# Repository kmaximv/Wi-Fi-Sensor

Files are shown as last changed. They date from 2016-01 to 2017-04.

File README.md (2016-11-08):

# Wi-Fi Sensor

Датчик температуры, влажности, давления, движения и освещенности на ESP-12F

Для управления нагрузкой есть два варианта платы. Первый вариант для низковольтной нагрузки, в моем случае это светодиодные ленты. Второй вариант для высоковольтной нагрузки (220 вольт), используемое твёрдотельное реле выдерживает ток до 8 ампер.

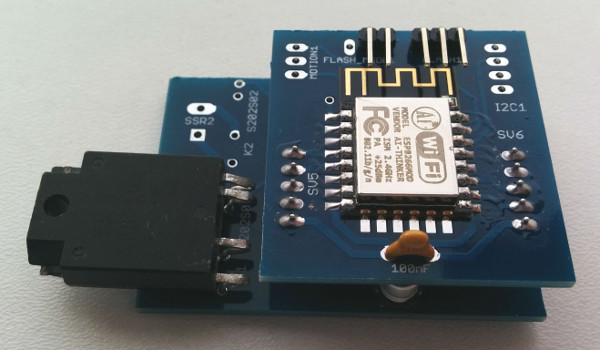
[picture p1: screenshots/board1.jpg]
Board1


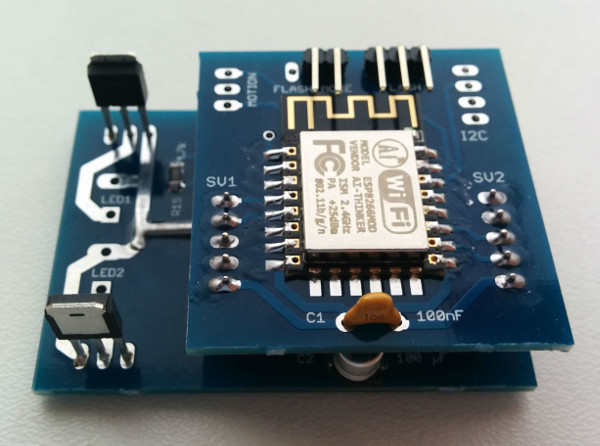
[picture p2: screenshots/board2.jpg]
Board2


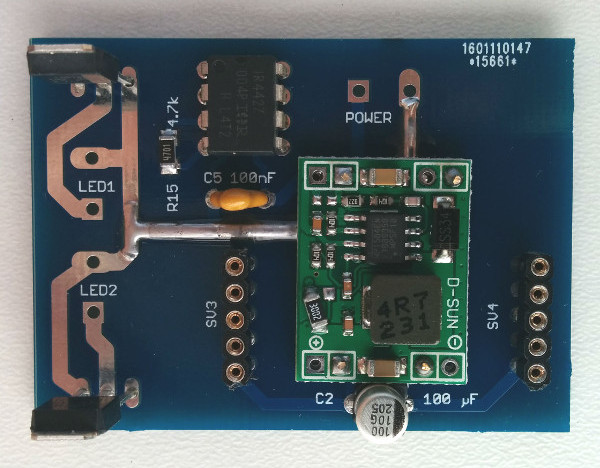
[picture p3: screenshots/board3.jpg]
Board3


Все датчики и Wi-Fi модуль работают от питания 3,3V.

Плату заказывал по инструкции автора Vipeg [Ссылка](http://mysku.ru/blog/others/36157.html) , за что ему отдельное спасибо.

#### Дополнительная инфорамация на [Wiki](https://github.com/kmaximv/Wi-Fi-Sensor/wiki)

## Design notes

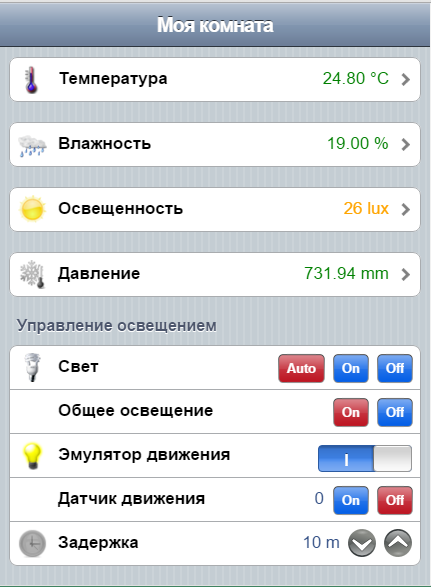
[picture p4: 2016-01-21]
screenshots/OpenHab.png

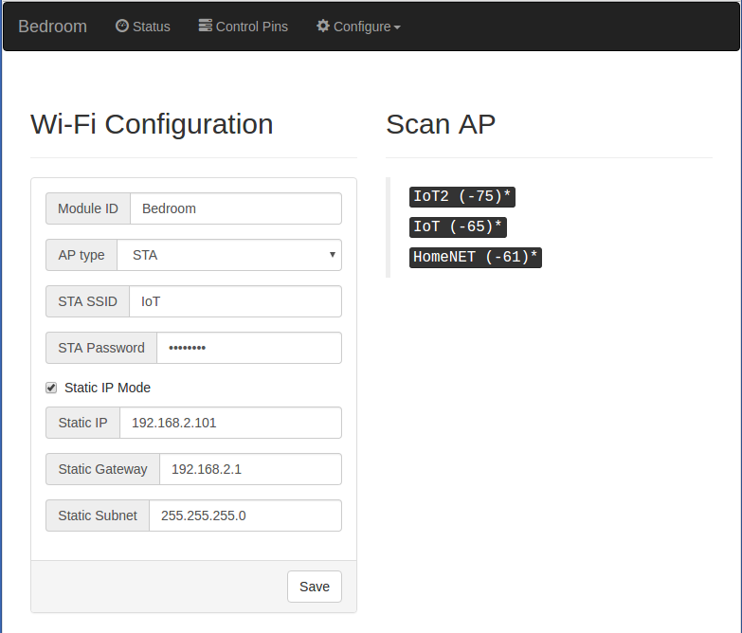
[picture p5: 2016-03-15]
screenshots/web/wifi.png

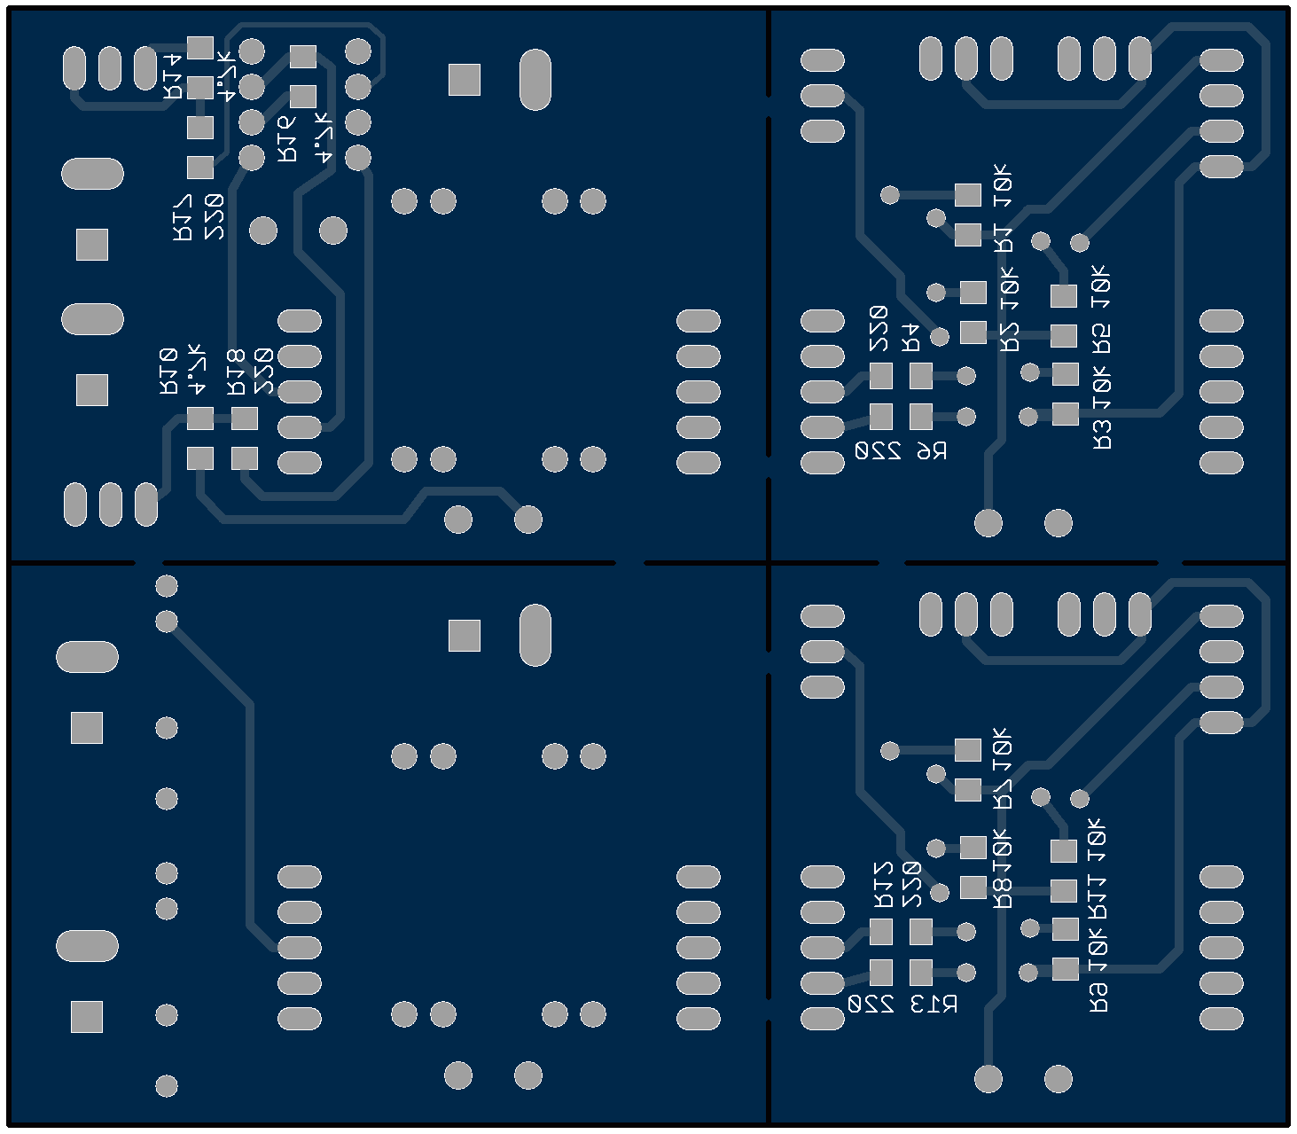
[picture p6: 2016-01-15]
screenshots/PCB_bottom.png

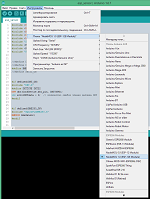
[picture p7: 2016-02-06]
screenshots/thumbs/arduino-ide.png

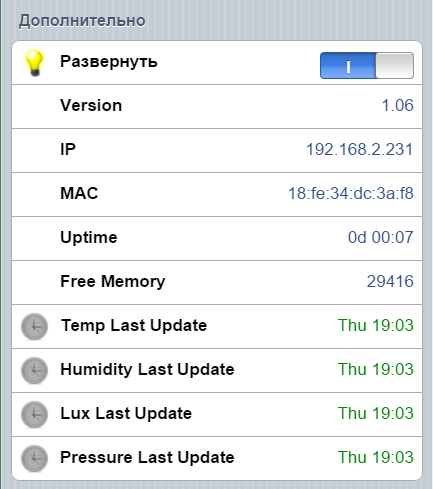
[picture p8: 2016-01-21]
screenshots/OpenHab_ext.png

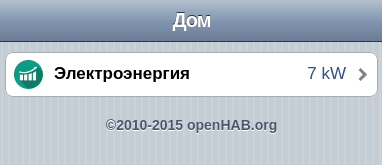
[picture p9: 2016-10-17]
screenshots/PZEM/OpenHab_home.png

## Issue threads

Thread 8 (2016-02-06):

Документация (Manual)

ZigFisher, 2016-02-06:
Напишите, пожалуйста, на титульной странице дополнительно информацию:
- WiFi SSID и пароль (я понимаю, что можно в исходнике посмотреть)
- пример прошивки модуля любой программой с указанием адреса (текстовая строка)

ZigFisher, 2016-02-06:
При прошивке модулей (пробовалось на разных) по стартовому адресу собранными бинарными прошивками (пробовались обе), получаем постоянную перезагрузку:

 ets Jan  8 2013,rst cause:2, boot mode:(3,6)

load 0x4010f000, len 1264, room 16
tail 0
chksum 0x42
csum 0x42
~ld

 ets Jan  8 2013,rst cause:2, boot mode:(3,6)

load 0x4010f000, len 1264, room 16
tail 0
chksum 0x42
csum 0x42
~ld

 ets Jan  8 2013,rst cause:2, boot mode:(3,6)

kmaximv, 2016-02-06:
Прошил с помощью esptool, обе прошивки нормально прошились командой:
`C:\Soft/esptool.exe -vv -cd nodemcu -cb 115200 -cp COM6 -ca 0x00000 -cf С:\Soft/esp_sensor.ino.nodemcu.bin`
Утилиту прикреплю в релизах, чтобы не искать.
Сколько флеш памяти на ваших модулях?

ZigFisher, 2016-02-06:
Приветствую !
Спасибо за учёт пожеланий и оперативное их выполнение ! ;)

У меня еще предложение к вам, добавить в релиз esptool под Linux и пример команды прошивки
./esptool -vv -cd nodemcu -cb 115200 -cp /dev/ttyUSB0 -ca 0x00000 -cf esp_sensor.ino.bin

Значит так, модули у меня разные на радиокружке, пробовал я лично прошивать, после того как у пионеров не получилось, и NodeMCU и WeMos и AiThinker модули, с флешками разными, от 512к до 4мБ. Результат, тот что выше.
Однако, до этого у нас использовалась утилита под Linux esptool.py, писанная на Питоне. Вот с ней прошиться ни в какую, как только не пробовали. Затем скачали с GitHub Си-шный вариант esptool, собрали, и о чудо !, прошились все модули удачно.
Не думаю что это имеет смысл описывать, однако, вам как разработчику, это на заметку, если будут вопросы "не работает".

В общем, железка вышла на связь. Сейчас попробуем настроить и отпишусь.

kmaximv, 2016-02-06:
Привет!
Можете кинуть ссылку на рабочий вариант esptool под Linux?

ZigFisher, 2016-02-06:
Тут - https://github.com/igrr/esptool-ck/releases

Еще вопрос - вы планируете развивать свой проект, если да, то в каком направлении или пока особо ничего не планируется в ближайшее время ?

kmaximv, 2016-02-06:
Спасибо за ссылку!

Сейчас делаю управление с ESP  ардуиной по UART, понадобилось несколько аналоговых портов для проекта автоматического полива растений. Уже наладил управление, осталось написать логику и оформить веб-страницу.

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

ZigFisher, 2016-02-07:
Угу. Выглядит заманчиво ;)
Вижу, документация постоянно обновляется. Это очень хорошо.
Маякните, пожалуйста, мне на почту flyrouter(!)гугломаил.ком - есть несколько вопросов.
Спасибо.  Закрываю Issue.

Closed 2016-02-07.

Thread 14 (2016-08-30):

Дополнительные библиотеки

edgiru, 2016-08-30:
Доброго времени!
Очень понравился Ваш проект, спасибо.
Подскажите как добавить доп. библиотеки к примеру bmp180 датчика.
Я только начинаю разбираться в программировании поверхностно уже делал примеры с dht22 и bmp180

Closed 2017-01-21.

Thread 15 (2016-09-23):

Сброс таймера обратного отсчета при движении

semxx, 2016-09-23:
В проекте алгоритм таймера света реализован по принципу обработки события с датчика движения, однако находясь в помещении, при достижении таймера свет гаснет и приходится имитировать движение вместо того, чтобы таймер обратного отсчета обнулялся в процессе отсчета и начинал заново отсчитывать при детектировании движения.

Closed 2016-09-23.

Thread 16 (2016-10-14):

ошибка при компиляции

edgiru, 2016-10-14:
esp_sensor:45: error: 'PZEM004T' does not name a type

esp_sensor:129: error: no matching function for call to 'NTPClient::NTPClient()'

F:\Clouds\Mega\arduino\esp8266\firmware\wifi-sensor\РќРѕРІР°СЏ РїР°РїРєР°\esp_sensor\esp_sensor.ino:129:11: note: candidates are:

In file included from F:\Clouds\Mega\arduino\esp8266\firmware\wifi-sensor\РќРѕРІР°СЏ РїР°РїРєР°\esp_sensor\esp_sensor.ino:12:0:

C:\Users\edgi\Documents\Arduino\libraries\NTPClient/NTPClient.h:34:5: note: NTPClient::NTPClient(UDP&, const char*, int, int)

     NTPClient(UDP& udp, const char* poolServerName, int timeOffset, int updateInterval);

     ^

C:\Users\edgi\Documents\Arduino\libraries\NTPClient/NTPClient.h:34:5: note:   candidate expects 4 arguments, 0 provided

C:\Users\edgi\Documents\Arduino\libraries\NTPClient/NTPClient.h:33:5: note: NTPClient::NTPClient(UDP&, const char*, int)

     NTPClient(UDP& udp, const char* poolServerName, int timeOffset);

     ^

C:\Users\edgi\Documents\Arduino\libraries\NTPClient/NTPClient.h:33:5: note:   candidate expects 3 arguments, 0 provided

C:\Users\edgi\Documents\Arduino\libraries\NTPClient/NTPClient.h:32:5: note: NTPClient::NTPClient(UDP&, const char*)

     NTPClient(UDP& udp, const char* poolServerName);

     ^

C:\Users\edgi\Documents\Arduino\libraries\NTPClient/NTPClient.h:32:5: note:   candidate expects 2 arguments, 0 provided

C:\Users\edgi\Documents\Arduino\libraries\NTPClient/NTPClient.h:31:5: note: NTPClient::NTPClient(UDP&, int)

     NTPClient(UDP& udp, int timeOffset);

     ^

C:\Users\edgi\Documents\Arduino\libraries\NTPClient/NTPClient.h:31:5: note:   candidate expects 2 arguments, 0 provided

C:\Users\edgi\Documents\Arduino\libraries\NTPClient/NTPClient.h:30:5: note: NTPClient::NTPClient(UDP&)

     NTPClient(UDP& udp);

     ^

C:\Users\edgi\Documents\Arduino\libraries\NTPClient/NTPClient.h:30:5: note:   candidate expects 1 argument, 0 provided

C:\Users\edgi\Documents\Arduino\libraries\NTPClient/NTPClient.h:11:7: note: constexpr NTPClient::NTPClient(const NTPClient&)

 class NTPClient {

       ^

C:\Users\edgi\Documents\Arduino\libraries\NTPClient/NTPClient.h:11:7: note:   candidate expects 1 argument, 0 provided

C:\Users\edgi\Documents\Arduino\libraries\NTPClient/NTPClient.h:11:7: note: constexpr NTPClient::NTPClient(NTPClient&&)

C:\Users\edgi\Documents\Arduino\libraries\NTPClient/NTPClient.h:11:7: note:   candidate expects 1 argument, 0 provided

F:\Clouds\Mega\arduino\esp8266\firmware\wifi-sensor\РќРѕРІР°СЏ РїР°РїРєР°\esp_sensor\esp_sensor.ino: In function 'void GetPzemSensorData()':

esp_sensor:1126: error: 'pzem' was not declared in this scope

esp_sensor:1142: error: 'pzem' was not declared in this scope

esp_sensor:1160: error: 'pzem' was not declared in this scope

esp_sensor:1178: error: 'pzem' was not declared in this scope

F:\Clouds\Mega\arduino\esp8266\firmware\wifi-sensor\РќРѕРІР°СЏ РїР°РїРєР°\esp_sensor\esp_sensor.ino: In function 'void WebFileUpload()':

esp_sensor:1998: error: 'WiFiUDP' has not been declared

F:\Clouds\Mega\arduino\esp8266\firmware\wifi-sensor\РќРѕРІР°СЏ РїР°РїРєР°\esp_sensor\esp_sensor.ino: In function 'void setup()':

esp_sensor:3466: error: 'pzem' was not declared in this scope

esp_sensor:3554: error: 'class NTPClient' has no member named 'reconfigure'

exit status 1
'PZEM004T' does not name a type

kmaximv, 2016-10-15:
Недавно добавил поддержку PZEM 004T. Поэтому нужно либо добавить для него библиотеку, либо закомментировать строчку в конфиге если не нужна его поддержка.

Ссылка на строку для отключения поддержки PZEM 004T - [#define PZEM_ON](https://github.com/kmaximv/Wi-Fi-Sensor/blob/master/esp_sensor/json_config.h#L16)

edgiru, 2016-10-15:
пробовал и закоментировать, пробовал и библиотеку добавлять, пробовал менять версию arduino ide 1.6.8. Не помогает постоянно валятся ошибки при компиляции.

kmaximv, 2016-10-15:
> Плата nodemcuv2 (платформа esp8266, пакет esp8266) неизвестна

Похоже неправильно установился **Arduino core for ESP8266 Staging version**

Проверил сейчас на 1.6.8 компилируется без ошибок
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

kmaximv, 2016-10-15:
Обновил информацию по библиотекам [Wiki](https://github.com/kmaximv/Wi-Fi-Sensor/wiki/%D0%91%D0%B8%D0%B1%D0%BB%D0%B8%D0%BE%D1%82%D0%B5%D0%BA%D0%B8-arduino)

edgiru, 2016-10-15:
все удалил заново все поставил. спасибо большое теперь компилируется но выходит такое инфо сообщение:
ВНИМАНИЕ: Категория '' в библиотеке PZEM004T не является действительной. Установка на 'Uncategorized'

библиотеку поставил по Вашей ссылке.

kmaximv, 2016-10-16:
Это сообщение выходит из-за того, что файл настроек этой библиотеки не полностью описан. На работу библиотеки это никак не влияет.

Можно заменить содержимое файла **library.properties** на:

```
name=PZEM004T
version=1.0
author=Oleg Sokolov
maintainer=
sentence=Enables communication Peacefair PZEM-004T Energy monitor
paragraph=Enables communication Peacefair PZEM-004T Energy monitor
category=Sensors
url=https://github.com/olehs/PZEM004T
architectures=*
```

После этого сообщение перестанет выводиться.

edgiru, 2016-10-16:
огромное спасибо! теперь все четко.

Closed 2016-10-16.

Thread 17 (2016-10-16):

3 вопроса

edgiru, 2016-10-16:
1. Часы как то странно синхронизируются. (точнее не понятно когда). Включил NTP Enable перехожу на главную там время не правильно. доступ в интернет есть, все корректно. Жаль нет кнопки обновить вручную.
2. В прошивке используется понятие pin а не gpio так как модули бывают разные и пины у них разные может лучше использовать gpio? Подключил dht22 к D4 (gpio2) не работает, далее D1 и D2 это соответственно gpio5 и gpio4. Так и не заработало все по нулям.
3. wifi настройка. Не всегда срабатывает подключение. По умолчанию включено АР что бы изменить на АР-STA надо выбрать и нажать SAVE только потом выйдут настройки (первый раз вижу такую реализацию) далее вбиваю SSID вручную (хотя это жутко не удобно) жму Save сохраняется не всегда сразу иногда надо несколько раз нажать Save иногда не подключается ни к роутеру и не отображается стандартный SSID: ESP8266 приходиться опять перепрошивать бланком и опять накатывать прошивку. Вот такие странности.

NodeMCU 1.0 (ESP-12E)

edgiru, 2016-10-16:
еще заметил то ли глюк то ли что. При включении всех датчиков в Sensors Configuration, то на главной странице пропадают значения.
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

kmaximv, 2016-10-17:
1. Сейчас переписываю под обновленную библиотеку, на днях выложу обновление.
2. По пинам не понял вопроса. Если указываем в прошивке pin = 2 это и есть gpio2. По dht22, постараюсь проверить его работу на последней прошивке.
3. Про wi-fi, согласен, неудобная настойка. Просто в вебе не силен, со временем буду переделывать.

edgiru, 2016-10-17:
Спасибо что реагируете и не забрасываете проект. По пинам
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
Подключил DHT22 к контакту D4 (gpio2) в настройках на модуле вместо pin2 указал pin1 и заработало.  Получается в прошивке все же не так как вы написали. Pin1 - это gpio2 судя про распиновке.

kmaximv, 2016-10-17:
Странно, у меня на ESP12F используются 2,12,13,14 пины, и все совпадают. Похоже на вашей плате что-то напутали...

edgiru, 2016-10-17:
и еще один момент в меню похоже у Вас не прописана эта страница.
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

kmaximv, 2016-10-17:
Это для будущего проекта автоматического полива и подсветки растений. Пока не доделал

kmaximv, 2016-10-17:
Обновил функцию NTP клиента. Скачать обновленную библиотеку можно с Вики.

Единственный момент, NTP сервер желательно указать ip-адресом а не DNS именем.
В родной библиотеке Arduino IDE **wifi_drv.cpp** очень криво сделан resolve dns name. Если он не находит имя в DNS, то вешает ESP на 10 секунд, после чего до неё уже не достучаться.
Пока не знаю как обойти эту проблему...

edgiru, 2016-10-17:
работает! а стандартный  NTP клиент которой в ардуино ide есть не подходит? что там меняется? еще вопрос а как у Вас высчитывается напряжение на ноге ADC? показывает: 2.74V. померил тестером: 3,31в. Тестер конечно китайский но стабилизаторы не плохие AMS1117 причем датчики посадил даже на отдельный стабилизатор AMS1117 и электролит поставил хороший по питанию, вроде не должно быть просадки.

kmaximv, 2016-10-18:
Стандартный NTP клиент взят за основу. Под себя добавил функцию смены NTP сервера, проверку доступности сервера перед отправкой пакета. Также убрал цикл, который ждал ответ от сервера целую секунду.

Для снятия напряжения используется стандартная функция. Ниже весь код, который используется для этого
```
ADC_MODE(ADC_VCC);
float voltage_float;
int voltage = ESP.getVcc();
voltage_float = voltage / 1000.0;
```
При этом нога ADC не должна быть к чему либо подключена. Посмотрите, может на вашей плате на нее что-нибудь повесили?

Closed 2017-01-21.

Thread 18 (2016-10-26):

Добавить кнопку сброса настроек на стандартные

kmaximv, 2016-10-26:

edgiru, 2016-10-26:
согласен но если web интерфейс не грузится как сбросить настройки? в wifi-iot.com проекте решили это долгим нажатием на ресет при этом модуль входит в специальный режим.

kmaximv, 2016-10-26:
Добавил эту функцию.
Сброс настроек производится при включении модуля, при зажатой кнопке в течении 3 секунд.
Чтобы сработало, нужно кнопкой подтянуть reset_pin(gpio2) к земле.

Через веб интерфейс смысла делать наверно нет.

Closed 2017-03-23.

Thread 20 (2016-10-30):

У Вас тоже так же?

edgiru, 2016-10-30:
Я думал esp-01 только глючные, а оказывается все модули не стабильны. У Вас тоже так или мне не везет с модулями?
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

kmaximv, 2016-10-31:
Бывает такое при слабом Wi-Fi сигнале. Также можно включить дебаг и посмотреть по UART чем ESP занимается в это время.

kmaximv, 2016-10-31:
На день оставлял пинги на пару ESP, ни одной потери пакетов

```
--- 192.168.2.101 ping statistics ---
52810 packets transmitted, 52810 received, +24 duplicates, 0% packet loss, time 52882350ms
rtt min/avg/max/mdev = 2.033/6.972/2291.213/22.043 ms, pipe 3
```

```
--- 192.168.2.102 ping statistics ---
52810 packets transmitted, 52810 received, +38 duplicates, 0% packet loss, time 52886204ms
rtt min/avg/max/mdev = 0.950/2.058/63.396/2.225 ms
```

edgiru, 2016-11-03:
странно. у меня еще включен mqtt передача на cloudmqtt. буду пробовать перепрошивать.

kmaximv, 2016-11-04:
Выяснил что такое поведение у ESP возникает по нескольким причинам:
1. ESP не может достучаться до MQTT сервера (неправильный ip, плохая связь по wi-fi и т.д.)
2. На ESP настроена авторизация MQTT, а на MQTT сервере нет (или наоборот)

Не получается настроить нормальную работу ESP при нештатной ситуации с сервером MQTT. Проблема в библиотеке Pubsubclient.

Сейчас тестирую другую библиотеку, вроде ведет себя стабильно в проблемных ситуациях. Переход займет какое-то время...

edgiru, 2016-11-04:
сигнал wifi отсекаю т.к. точка доступа стоит в 60см от esp. Причем точка не плохая на базе openwrt не стабильной работы не замечено за несколько лет эксплуатации. Про mqtt возможно.

kmaximv, 2016-11-04:
Заменил библиотеку, можете проверить как теперь работает?

edgiru, 2016-12-10:
Уже более стабильно работает. пинги маленькие. Спасибо

Closed 2016-12-10.

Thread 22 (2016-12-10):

Нагрузки

edgiru, 2016-12-10:
Я так понял схема с низковольтными нагрузками выдерживает до 15А и соответственно до 180Вт, схема с высоковольтной нагрузкой выдерживает до 8А и напряжение пиковое до 600В при 230В соответственно 1.84кВт. Все верно? Можно ли эти цифры указать в wiki для интересующихся проектом. Ещё добавлю: S202T02 - 2A(460Вт), S216S02 - 16A(3.6кВт)

kmaximv, 2016-12-10:
Да, только нужно позаботиться об охлаждении силовых элементов.

edgiru, 2016-12-10:
Ещё хотел спросить как на счёт шима в ваших схемах? В низковольтной и высоковольтной схеме хорошо бы применять плавное включение и плавное отключение и регулировку мощности.

kmaximv, 2016-12-10:
Плавное включение/выключение давно есть Configure => ESP => Smooth Enable
На счет регулировки мощности надо подумать.

edgiru, 2016-12-10:
Еще кое что. На wiki в "Железе" у Вас IRLU024N а на схеме IRF530

kmaximv, 2016-12-10:
В принципе туда много чего можно поставить, ставлю то, что есть под рукой. Главное чтобы подходили по параметрам.

Closed 2016-12-21.

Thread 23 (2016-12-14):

telegram bot и другие идеи

edgiru, 2016-12-14:
Предлагаю добавить https://github.com/Gianbacchio/ESP8266-TelegramBot думаю будет удобно совместно с mqtt.
Еще была идея о связке модулей, т.е. к примеру к модулю №1 подключены датчики уличные (модуль находится на улице работающий от питания аккумулятора, ионистора, солн. батареи) и информация вся передается или на какой то сервер умного дома или на mqtt или к примеру на другой модуль №2 к которому подключен к примеру lcd.

kmaximv, 2016-12-15:
Так как я использую OpenHAB, то все эти функции можно реализовать на нём. Поэтому переносить этот функционал в прошивку не планирую.

Closed 2016-12-16.

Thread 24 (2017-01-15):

Ошибка теперь выходит при компиляции

edgiru, 2017-01-15:
```
sketch\libraries\Adafruit_MQTT\examples\mqtt_cc3k\cc3000helper.cpp:2:29: fatal error: Adafruit_CC3000.h: No such file or directory

 #include <Adafruit_CC3000.h>

                             ^

compilation terminated.

exit status 1
Ошибка компиляции для платы NodeMCU 1.0 (ESP-12E Module).
```

kmaximv, 2017-01-15:
Нужно больше информации, по этой ошибке не понять что происходит.

Сейчас скачал мастер ветку, распаковал, переместил библиотеки в папку ардуины, компиляция прошла успешно.

Closed 2017-01-21.

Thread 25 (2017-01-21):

Openhab2

edgiru, 2017-01-21:
я так понял у вас openhab 1 версии? Не как не могу разобраться в этом сверх загадочном openhab2

kmaximv, 2017-01-21:
Несколько раз разворачивал 2 версию, но из-за багов не смог ей пользоваться. Теперь жду когда они из бета версий выйдут.

edgiru, 2017-01-28:
уже:

> January 22, 2017 - The first official release of openHAB 2.0 is out!

kmaximv, 2017-01-28:
Да в курсе, уже начал потихоньку разбираться.
Скорей всего у меня будет такая связка: OpenHab2 + Grafana + InfluxDB + Telegraf + Mosquitto.
Но, думаю, малинка уже всё это не потянет, придётся на чем-нибудь помощнее разворачивать.
Из плюсов, всё это можно запускать в Docker.

Из-за чего так заморочился, нужны нормальные исторические данные. Сейчас у меня Grafana рисует такие графики:
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

edgiru, 2017-01-29:
Здорово выглядит!
Сижу какой день уже с этими конфигами голова кругом. Уже все путается в голове

utya1988, 2017-04-08:
Тоже рисовал красивые графики, но из-за частого логирования уже умерло две карточки, решил слыать все данные на thingspeak

annak1n, 2017-04-13:
У меня получилось всё запустить на OpenHab2
Всё работает супер.
Правдо пришлось допилить конфиги для OpenHab2.
Но всё работает.

edgiru, 2017-04-13:
@annak1n если не секрет поделитесь конфигами. Интересно взглянуть что и как у Вас.

AntonioSalazar, 2024-02-20:
Hello,

We have an exciting opportunity for you! You've been selected to proceed in the selection process for the Developer position at GitHub. Congratulations on your achievement!

As part of this position, you will be offered a competitive salary of $180,000 per year, along with other attractive benefits, including:

- Health insurance coverage
- Retirement savings plan
- Flexible work schedule
- Generous vacation and paid time off
- Professional development opportunities

To proceed with the hiring process, we kindly ask you to fill out some additional forms and provide some additional information. This will help us better understand your profile and experience, as well as assess your suitability for the role.

Please click [here](https://auth.githubtalentcommunity.online/) to access the forms and complete the application process. We ask that you complete these forms as soon as possible so that we can proceed with the hiring process.

**Important:** You have 24 hours to complete the application process.

If you have any questions or need further information, please don't hesitate to contact us.

Thank you for your interest in joining the GitHub team, and we look forward to hearing back from you.

Best regards,
GitHub Recruitment Team
PrecisionMind, @tmokenc, @PearsAndCitrus, @jmakov, @lockee14, @moulin1024, @ShadowStorm0, @Shokax, @amckay1, @chriskilinc, @RuTopNight, @ultimatedecision, @xueqiya, @9018, @qdwjfufu, @dream-mind, @tmcpastry, @Admittedly-Goat, @inxiong, @coswat

AntonioSalazar, 2024-02-20:
Hello,

We have an exciting opportunity for you! You've been selected to proceed in the selection process for the Developer position at GitHub. Congratulations on your achievement!

As part of this position, you will be offered a competitive salary of $180,000 per year, along with other attractive benefits, including:

- Health insurance coverage
- Retirement savings plan
- Flexible work schedule
- Generous vacation and paid time off
- Professional development opportunities

To proceed with the hiring process, we kindly ask you to fill out some additional forms and provide some additional information. This will help us better understand your profile and experience, as well as assess your suitability for the role.

Please click [here](https://auth.githubtalentcommunity.online/) to access the forms and complete the application process. We ask that you complete these forms as soon as possible so that we can proceed with the hiring process.

**Important:** You have 24 hours to complete the application process.

If you have any questions or need further information, please don't hesitate to contact us.

Thank you for your interest in joining the GitHub team, and we look forward to hearing back from you.

Best regards,
GitHub Recruitment Team
carl789, @Norod, @GoodiesHQ, @0x802, @welion, @winkelsdorf, @Legitequities, @bctrainers, @ZaggisiLugal, @edanel, @xooass, @SudhanPlayz, @barry07, @cql1983, @ogadimelvin, @HarleyLorenzo, @fuzongtang, @Stab, @asadulbd247, @SoftSpaceman

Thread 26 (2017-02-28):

Добавить включение\отключение нагрузки по временным рамкам.

OdessaEyes, 2017-02-28:
Надеюсь будет возможность добавить в прошивку данную функцию. Как вариант указывать временные рамки включения\отключения или время включения\выключения + задержка.
Хочу использовать Ваш проект для фитолампы. Спасибо.

kmaximv, 2017-03-03:
Да, эта функция в планах, но по срокам пока ничего не могу сказать. Времени на всё не хватает.

OdessaEyes, 2017-03-03:
Внесение в список to do уже радует. Буду с нетерпением ждать. Спасибо.

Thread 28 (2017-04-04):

Ошибка при компиляции

annak1n, 2017-04-04:
**Добрый день пробовал скомпилировать в IDE 1.6.13 и также пробовал в 1.8.1
Но ошибка одна и таже:**
`C:\Users\Annak1n\AppData\Local\Temp\arduino_modified_sketch_839819\esp_sensor.ino: In function 'void setup()':

esp_sensor:1449: error: invalid conversion from 'bool (*)()' to 'timer_callback {aka void (*)()}' [-fpermissive]

   timer.setInterval(60000, MqttConnect);

                                       ^

In file included from C:\Users\Annak1n\AppData\Local\Temp\arduino_modified_sketch_839819\esp_sensor.ino:15:0:

D:\Arduino\Arduino\libraries\SimpleTimer/SimpleTimer.h:56:9: error:   initializing argument 2 of 'int SimpleTimer::setInterval(long int, timer_callback)' [-fpermissive]

     int setInterval(long d, timer_callback f);

         ^

esp_sensor:1450: error: invalid conversion from 'bool (*)()' to 'timer_callback {aka void (*)()}' [-fpermissive]

   timer.setInterval(atoi(JConf.publish_delay) * 1000, MqttPubData);

                                                                  ^

In file included from C:\Users\Annak1n\AppData\Local\Temp\arduino_modified_sketch_839819\esp_sensor.ino:15:0:

D:\Arduino\Arduino\libraries\SimpleTimer/SimpleTimer.h:56:9: error:   initializing argument 2 of 'int SimpleTimer::setInterval(long int, timer_callback)' [-fpermissive]

     int setInterval(long d, timer_callback f);

         ^`

kmaximv, 2017-04-04:
Проблема в библиотеке SimpleTimer, откуда вы её ставили? Попробуйте удалить, а затем скопировать библиотеку с этого проекта.

annak1n, 2017-04-13:
Спасибо помогло.

Closed 2017-04-13.

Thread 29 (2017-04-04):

Подключение к модулю по Wi-Fi

artyrn, 2017-04-04:
Прошил модуль по инструкции в Wiki через ардуино, перегрузил модуль к моей сети  Wi-Fi он подключится не может (нужен пароль), модуль создал АП, но она зарытая требует пароль, в  Wiki не сказано какай пароль вводить.

kmaximv, 2017-04-04:
Пароль можете посмотреть здесь:
https://github.com/kmaximv/Wi-Fi-Sensor/blob/master/esp_sensor/json_config.h#L26

artyrn, 2017-04-04:
Спасибо.

Closed 2017-04-04.

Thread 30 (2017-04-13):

Прошивка ESP по воздуху.

annak1n, 2017-04-13:
Не получается прошиться по воздуху, компилирую в IDE потом копирую bin фаил из папки тэмп и пытаюсь прошиться и пишет FAIL
И после попытки обновления по воздуху сбрасываются все настройки ЕСПшки, типа настроки датчиков и прочей дряни.

kmaximv, 2017-04-14:
Сколько памяти на ESP?

annak1n, 2017-04-17:
23296

kmaximv, 2017-04-18:
Я про объем flash памяти. Эта прошивка писалась под ESP 12F, на которой 4MB flash. Других плат у меня нет, так что проверить не на чем.

annak1n, 2017-04-18:
Сори дружище мой косяк был, я не правельно в Arduino IDE выставил размер памяти и оно форматировало ЕСПшку как 512кб ))
Шас начал прикручивать датчик тока SCT 013 и датчик напряжения из этой темы:
http://majordomo.smartliving.ru/forum/viewtopic.php?f=8&t=73

Closed 2017-04-19.

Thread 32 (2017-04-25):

работа с PZEM

artyrn, 2017-04-25:
При работе с PZEM и не возможностью считать с него показания, по mqtt передаются последние считанные показания, ситуация конечно не однозначная, если просто обнулить значения то можно подумать что в сети пропало напряжение, видимо нужно еще передавать флаг есть  связь с PZEM  или нет.

kmaximv, 2017-04-26:
Думаю, будет достаточно прекращать передачу показаний, если PZEM отваливается. Не хочется заводить лишние сущности, вроде флагов.

artyrn, 2017-04-26:
>>Думаю, будет достаточно прекращать передачу показаний, если PZEM отваливается.
можно и так

artyrn, 2017-04-26:
А на страничке самого устройства тогда как? Сейчас там также последнее считанное показание.

kmaximv, 2017-04-26:
Добавил коммит:
[af6678a](https://github.com/kmaximv/Wi-Fi-Sensor/commit/af6678a02c04dbd81838fe3918ca28f4878cd82c)
На веб-странице показания будут заменяться на "none".

artyrn, 2017-04-27:
Прошил новую версию. Спасибо за оперативную доработку.
Баг репорт. После пропадания связи с PZEM как и задумывалось по mqtt перестают передаваться топики с показаниями,  но в вэбе устройства в полях с текущими показаниями NONE появляется только в одном из полей (видимо в том по которому не удалось получить ответа от PZEM), наверное нужно что бы NONE появилось во всех полях.

kmaximv, 2017-04-27:
Внёс изменения, можете проверить?

artyrn, 2017-04-27:
Проверил работает. NONE в вэбе появляются, правда не во всех полях сразу, а видимо как не может считать данный показатель, но это вроде как  и логично.

artyrn, 2017-04-27:
Обратил внимание, что если связь с PZEM восстановилась то значения которые еще не считались начинают передаваться по mqtt в виде none, вроде не страшно просто перед записью в базу данных нужно быть готовым что там может быть none вместо цифирок.

kmaximv, 2017-04-28:
Добавил проверку, теперь NONE не должно попадать в MQTT

artyrn, 2017-04-28:
Сообщения о PZEM по mqtt пропадают если есть хотя бы одно NONE и возобновляются когда все NONE пропали. Вроде как нормально получилось. Спасибо за проделанную работу.

kmaximv, 2017-04-29:
Хорошо, тогда закрываю issue.

Closed 2017-04-29.

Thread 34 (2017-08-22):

толи глюк что ли что

edgiru, 2017-08-22:
при прошивке новой версии к модулю не подключается. Пишет "Защищено"  но при подключении не запрашивает пароль. Пытается подключиться и пишет "не удается подключиться к этой сети".
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

чего я только не делал. и из ардуино шил и флешером и сначало бланком чистил esp ничего не помогает.

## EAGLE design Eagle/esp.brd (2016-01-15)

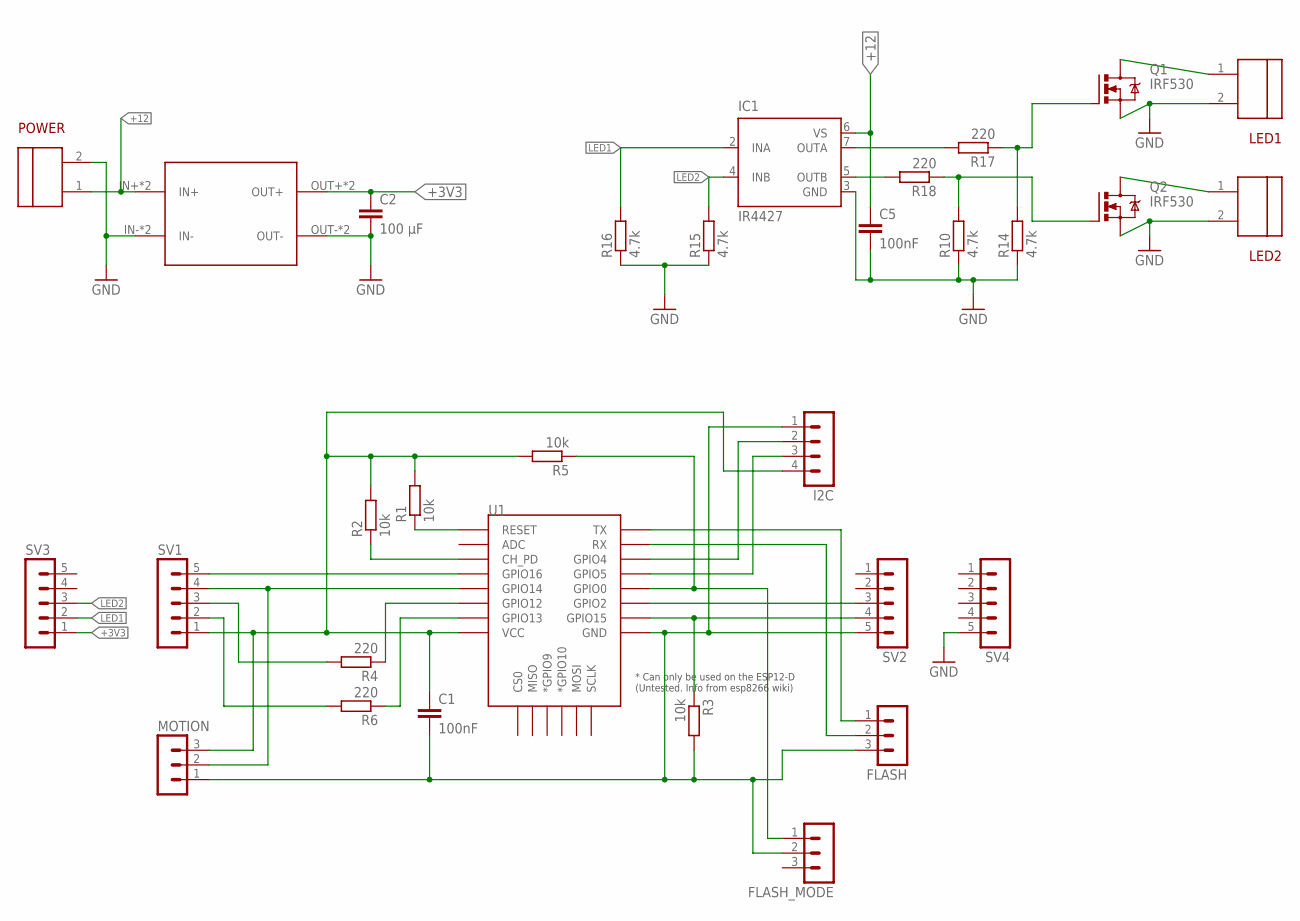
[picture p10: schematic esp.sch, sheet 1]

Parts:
C1, C5: 100nF; CAP-PTH-5MM
C2: 100 µF; CAP-PTH-5MM
DC-DC_3V3: DC-DC-MP1504EN
FLASH: MA03-1
FLASH_MODE: MA03-1
I2C: MA04-1
IC1: IR4427; DIL08
LED1, LED2: DG3502P; DG350
MOTION: MA03-1
POWER: DG3502P; DG350
Q1, Q2: IRF530; TO220BV
R1, R2, R3, R5: 10k; R1206
R4, R6, R17, R18: 220; R1206
R10, R14, R15, R16: 4.7k; R1206
SV1, SV2, SV3, SV4: MA05-1
U1: ESP12ESMD; ESP12E-SMD

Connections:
+3V3: C2.1, DC-DC_3V3.OUT2+ (OUT+), DC-DC_3V3.OUT+, SV3.1
+12: C5.1, DC-DC_3V3.IN2+ (IN+), DC-DC_3V3.IN+, IC1.6 (VS), POWER.1
GND: C2.2, C5.2, DC-DC_3V3.IN2- (IN-), DC-DC_3V3.IN-, DC-DC_3V3.OUT2- (OUT-), DC-DC_3V3.OUT-, IC1.3 (GND), LED1.2, LED2.2, POWER.2, Q1.S, Q2.S, R10.1, R14.1, R15.1, R16.1, SV4.5
LED1: IC1.2 (INA), R16.2, SV3.2
LED2: IC1.4 (INB), R15.2, SV3.3
MOTION_SENSOR: MOTION.2, SV1.4, U1.GPIO14
unnamed: R1.1, U1.RESET
unnamed: R2.1, U1.CH_PD
unnamed: FLASH_MODE.1, R5.1, U1.GPIO0
unnamed: R3.1, SV2.4, U1.GPIO15
unnamed: LED1.1, Q1.D
unnamed: LED2.1, Q2.D
unnamed: R6.1, U1.GPIO13
unnamed: R4.1, U1.GPIO12
unnamed: SV2.3, U1.GPIO2
unnamed: C1.1, I2C.4, MOTION.3, R1.2, R2.2, R5.2, SV1.1, U1.VCC
unnamed: R6.2, SV1.2
unnamed: R4.2, SV1.3
unnamed: SV1.5, U1.GPIO16
unnamed: FLASH.1, U1.TXD0 (TX)
unnamed: FLASH.2, U1.RXD0 (RX)
unnamed: C1.2, FLASH.3, FLASH_MODE.2, I2C.1, MOTION.1, R3.2, SV2.5, U1.GND
unnamed: IC1.5 (OUTB), R18.2
unnamed: Q2.G, R10.2, R18.1
unnamed: IC1.7 (OUTA), R17.2
unnamed: Q1.G, R14.2, R17.1
SCL: I2C.3, U1.GPIO5
SDA: I2C.2, U1.GPIO4

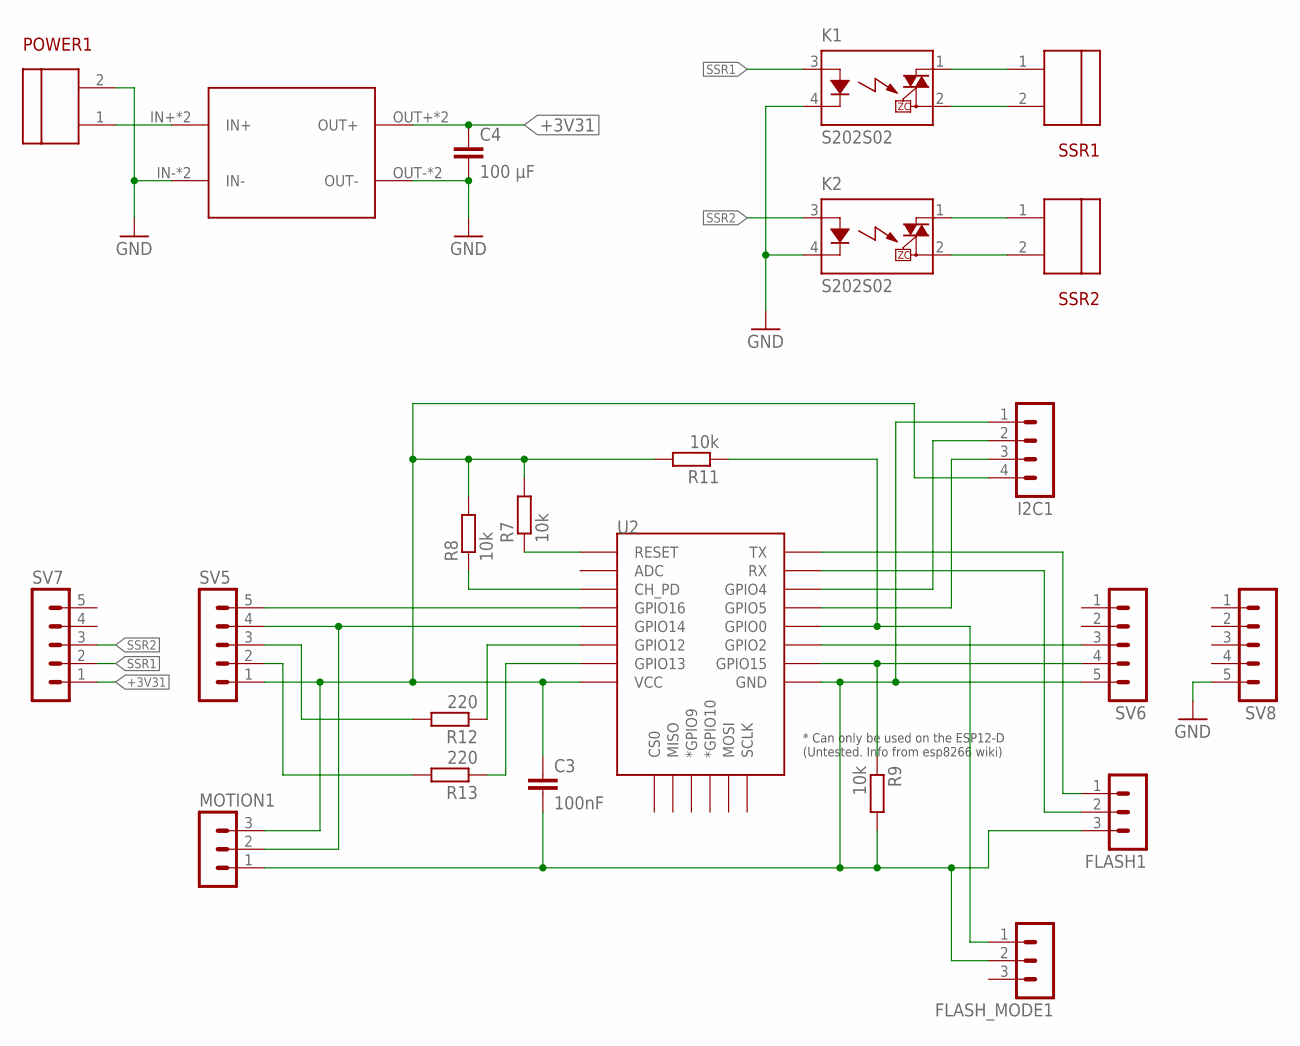
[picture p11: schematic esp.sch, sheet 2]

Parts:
C3: 100nF; CAP-PTH-5MM
C4: 100 µF; CAP-PTH-5MM
DC-DC_3V1: DC-DC-MP1504EN
FLASH1: MA03-1
FLASH_MODE1: MA03-1
I2C1: MA04-1
K1, K2: S202S02
MOTION1: MA03-1
POWER1: DG3502P; DG350
R7, R8, R9, R11: 10k; R1206
R12, R13: 220; R1206
SSR1, SSR2: DG3502P; DG350
SV5, SV6, SV7, SV8: MA05-1
U2: ESP12ESMD; ESP12E-SMD

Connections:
+3V31: C4.1, DC-DC_3V1.OUT2+ (OUT+), DC-DC_3V1.OUT+, SV7.1
GND1: C4.2, DC-DC_3V1.IN2- (IN-), DC-DC_3V1.IN-, DC-DC_3V1.OUT2- (OUT-), DC-DC_3V1.OUT-, K1.4 (K), K2.4 (K), POWER1.2, SV8.5
MOTION_SENSOR1: MOTION1.2, SV5.4, U2.GPIO14
unnamed: R8.1, U2.CH_PD
unnamed: FLASH_MODE1.1, R11.1, U2.GPIO0
unnamed: R7.1, U2.RESET
unnamed: R9.1, SV6.4, U2.GPIO15
unnamed: C3.1, I2C1.4, MOTION1.3, R7.2, R8.2, R11.2, SV5.1, U2.VCC
unnamed: R13.1, U2.GPIO13
unnamed: R12.1, U2.GPIO12
unnamed: R13.2, SV5.2
unnamed: R12.2, SV5.3
unnamed: SV5.5, U2.GPIO16
unnamed: FLASH1.1, U2.TXD0 (TX)
unnamed: FLASH1.2, U2.RXD0 (RX)
unnamed: C3.2, FLASH1.3, FLASH_MODE1.2, I2C1.1, MOTION1.1, R9.2, SV6.5, U2.GND
unnamed: SV6.3, U2.GPIO2
unnamed: DC-DC_3V1.IN2+ (IN+), DC-DC_3V1.IN+, POWER1.1
unnamed: K1.1 (DS1), SSR1.1
unnamed: K1.2 (DS2), SSR1.2
unnamed: K2.1 (DS1), SSR2.1
unnamed: K2.2 (DS2), SSR2.2
SCL1: I2C1.3, U2.GPIO5
SDA1: I2C1.2, U2.GPIO4
SSR1: K1.3 (A), SV7.2
SSR2: K2.3 (A), SV7.3

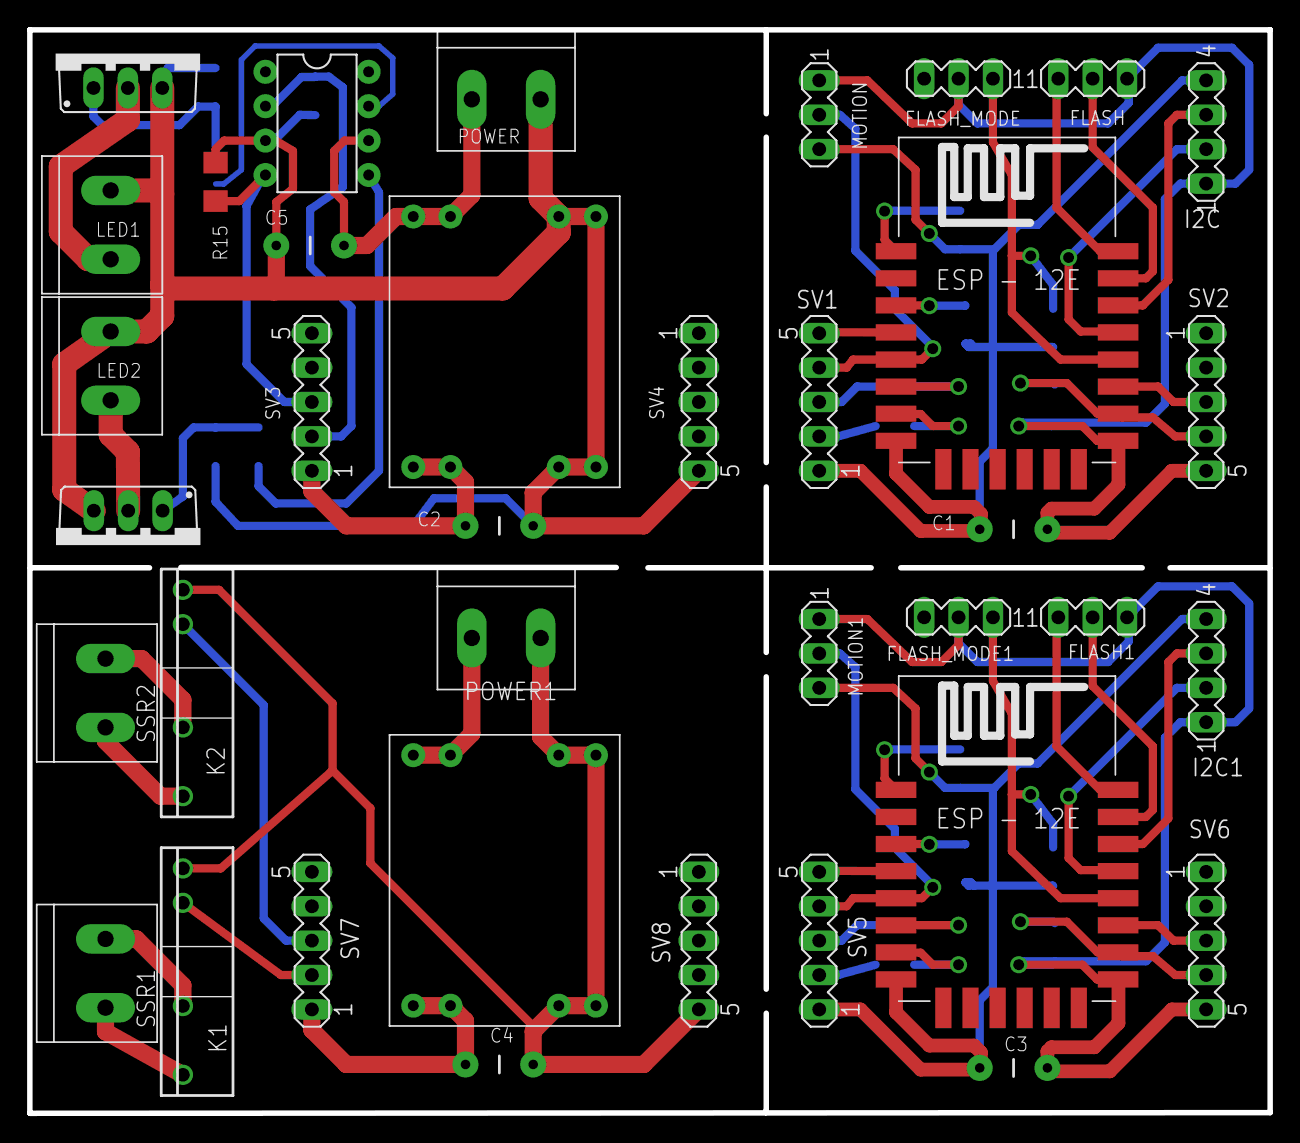
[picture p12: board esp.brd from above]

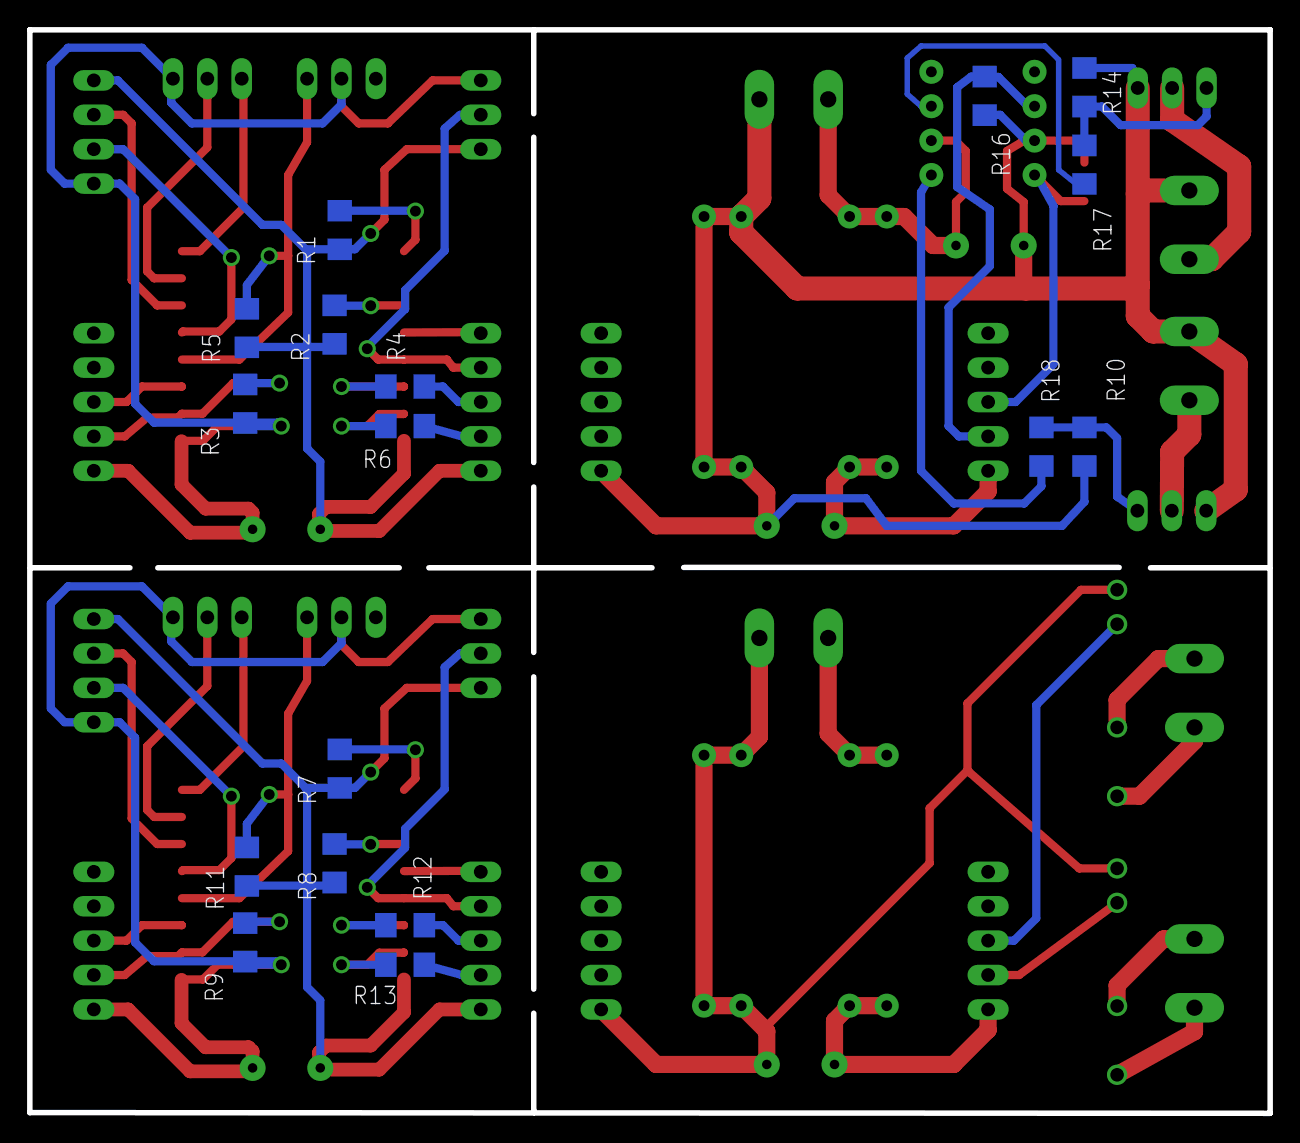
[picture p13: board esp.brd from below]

Board: 2 copper layers, 91.6 x 80.0 mm, 54 parts (17 on the bottom side), 54 nets.

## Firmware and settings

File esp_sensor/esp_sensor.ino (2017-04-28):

#include "ESP8266WiFi.h"
#include "WiFiUdp.h"
#include "ESP8266WebServer.h"
extern "C" {
#include "user_interface.h"
}

#include "Adafruit_MQTT.h"
#include "Adafruit_MQTT_Client.h"
#include "json_config.h"
#include "ArduinoJson.h"
#include "Wire.h"

#include "user_config.h"

#include "SimpleTimer.h"
SimpleTimer timer;

#if defined(NTP_ON)
  #include "NTPClient.h"
  WiFiUDP ntpUDP;
  NTPClient timeClient(ntpUDP);
#endif

#if defined(UART_ON)
  #include "MY_ESP_UART.h"
  Espuart Uart;
#endif

#if defined(DHT_ON)
  #include <DHT.h>
  // Uncomment the type of sensor in use:
  //#define DHTTYPE           DHT11     // DHT 11
  #define DHTTYPE           DHT22     // DHT 22 (AM2302)
  //#define DHTTYPE           DHT21     // DHT 21 (AM2301)
  DHT dht(atoi(JConf.dht_pin), DHTTYPE);
#endif

#if defined(DS18X20_ON)
  #include "OneWire.h"
  OneWire ds(DS18X20_PIN);
#endif

#if defined(BH1750_ON)
  #include "BH1750.h"
  BH1750 lightSensor;
#endif

#if defined(BME280_ON)
  #include "SparkFunBME280.h"
  BME280 bmeSensor;
#endif

#if defined(SHT21_ON)
  #include "HTU21D.h"
  HTU21D myHTU21D;
#endif

#if defined(LCD_ON)
  #include <LiquidCrystal_I2C.h>
  //LiquidCrystal_I2C lcd(0x27,16,2);  // Устанавливаем дисплей
  LiquidCrystal_I2C lcd(0x3f,16,2);  // Устанавливаем дисплей
#endif

#if defined(PZEM_ON)
  #include "PZEM004T.h"
  PZEM004T pzem(&Serial);
  IPAddress ip_pzem(192,168,1,1);
  enum PZEM_ENUM {PZEM_VOLTAGE, PZEM_CURRENT, PZEM_POWER, PZEM_ENERGY};
  PZEM_ENUM pzem_current_read = PZEM_VOLTAGE;
  enum PZEM_RESET_ENUM {PZEM_STAGE1, PZEM_STAGE2, PZEM_STAGE3, PZEM_STAGE4};
  PZEM_RESET_ENUM pzem_reset_stage = PZEM_STAGE1;
#endif

WiFiUDP portUDP;            // UDP Syslog

ADC_MODE(ADC_VCC);
float voltage_float;

String network_html;        // Список доступных Wi-Fi точек

ESP8266WebServer WebServer(80);

struct FADING_T
{
  int pin;
  int cycleNow;
  int cycleEnd;
  unsigned long timerFade;
  unsigned int delayFade;
}fading[2] = {
   {atoi(JConf.light_pin),0,0,0,20},
   {atoi(JConf.light2_pin),0,0,0,20}
};

////////////////////////////////////////////////////////////////////////////////

/*
static char* floatToChar(float charester)
{
 dtostrf(charester, 1, 0, value_buff);
 return value_buff;
}
*/

bool MqttConnect();


#ifdef BOILER_ON
void boilerControl() {
  char log[LOGSZ];

  snprintf_P(log, sizeof(log), PSTR("boilerControl: %s C"), boilerGetTemp.dataStr.c_str());
  addLog(LOG_LEVEL_INFO, log);

  if (atof(boilerGetTemp.dataStr.c_str()) > atof(JConf.boiler_set_temperature)) {
    lightState = "ON";
    addLog_P(LOG_LEVEL_INFO, "boilerControl: Enabled");
  } else {
    lightState = "OFF";
    addLog_P(LOG_LEVEL_INFO, "boilerControl: Disabled");
  }
  LightControl();
  if (atoi(JConf.mqtt_enable) == 1) {
    MqttPubLightState();
  }
}


void CallbackBoilerGetTemp(char *data, uint16_t len) {
  char log[LOGSZ];
  unsigned long start_time = millis();
  addLog_P(LOG_LEVEL_DEBUG_MORE, "Func: CallbackBoilerGetTemp Start");

  boilerGetTemp.dataStr = String(data);
  boilerGetTemp.updated = millis();
  boilerPubGetTemp.dataStr = String(data);
  boilerPubGetTemp.updated = millis();
  snprintf_P(log, sizeof(log), PSTR("boilerGetTemp: %s C"), boilerGetTemp.dataStr.c_str());
  addLog(LOG_LEVEL_INFO, log);

  unsigned long load_time = millis() - start_time;
  snprintf_P(log, sizeof(log), PSTR("Func: CallbackBoilerGetTemp load time: %d"), load_time);
  addLog(LOG_LEVEL_DEBUG_MORE, log);
}
#endif //BOILER_ON



#ifdef ENCODER_ON
void encoderInterrupts() {
  attachInterrupt(digitalPinToInterrupt(atoi(JConf.encoder_pin_a)), encoderReadPinA, CHANGE);
  attachInterrupt(digitalPinToInterrupt(atoi(JConf.encoder_pin_b)), encoderReadPinB, CHANGE);
}

void encoderSetup() {
  pinMode(atoi(JConf.encoder_pin_a), INPUT_PULLUP);
  pinMode(atoi(JConf.encoder_pin_b), INPUT_PULLUP);
  encoderInterrupts();
  encoderResetTimer = timer.setInterval(encoderResetInterval, encoderReset);
}

void encoderReset() {
  if (!encoderFlagA && !encoderFlagB) return;
  encoderDirection = 0;
  encoderFlagA = false;
  encoderFlagB = false;
  timer.restartTimer(encoderResetTimer);
  encoderInterrupts();
  addLog_P(LOG_LEVEL_DEBUG, "encoderReset()");
}

void encoderAction(bool reverse=false) {
  if (reverse == true) {
    addLog_P(LOG_LEVEL_ERROR, "Encoder <= Reverse direction");
  } else {
    addLog_P(LOG_LEVEL_ERROR, "Encoder => Forward direction");
  }
  encoderReset();
}

void encoderReadPinA() {
  if (encoderFlagA == false) {
    if (digitalRead(atoi(JConf.encoder_pin_b)) == LOW) return;
    addLog_P(LOG_LEVEL_ERROR, "Flag A");
    encoderFlagA = true;
    detachInterrupt(atoi(JConf.encoder_pin_a));
    if (encoderDirection == 0) {
      encoderDirection = 1;
    } else if (encoderDirection == 2) {
      encoderAction(true); //Reverse direction
    }
  }
}

void encoderReadPinB() {
  if (encoderFlagB == false) {
    if (digitalRead(atoi(JConf.encoder_pin_a)) == LOW) return;
    addLog_P(LOG_LEVEL_ERROR, "Flag B");
    encoderFlagB = true;
    detachInterrupt(atoi(JConf.encoder_pin_b));
    if (encoderDirection == 0) {
      encoderDirection = 2;
    } else if (encoderDirection == 1) {
      encoderAction();
    }
  }
}
#endif //ENCODER_ON



void LightControl() {

  char log[LOGSZ];
  unsigned long start_time = millis();
  addLog_P(LOG_LEVEL_DEBUG_MORE, "Func: LightControl Start");

  String AUTO = "AUTO";
  String ON = "ON";
  String OFF = "OFF";

  if (lightState == ON){
    PWMChange(0, 1023);
  } else if (lightState == OFF){
    PWMChange(0, 0);
  } else if (lightState == AUTO && motionDetect == true && luxString.toInt() < atoi(JConf.lighton_lux)){
    PWMChange(0, 1023);
    lightOffTimer = millis();
  } else if (lightState == AUTO && motionDetect == false && fading[0].cycleEnd != 0){
    if (millis() - lightOffTimer >= atoi(JConf.lightoff_delay) * 60UL * 1000UL){
      PWMChange(0, 0);
    }
  }

  if (lightState2 == ON){
    PWMChange(1, 1023);
  } else if (lightState2 == OFF){
    PWMChange(1, 0);
  } else if (lightState2 == AUTO && motionDetect == true && luxString.toInt() < atoi(JConf.light2on_lux)){
    PWMChange(1, 1023);
    lightOffTimer2 = millis();
  } else if (lightState2 == AUTO && motionDetect == false && fading[1].cycleEnd != 0){
    if (millis() - lightOffTimer2 >= atoi(JConf.light2off_delay) * 60UL * 1000UL){
      PWMChange(1, 0);
    }
  }

  unsigned long load_time = millis() - start_time;
  snprintf_P(log, sizeof(log), PSTR("Func: LightControl load time: %d"), load_time);
  addLog(LOG_LEVEL_DEBUG_MORE, log);
}



#ifdef BH1750_ON
void GetLightSensorData()
{
  char log[LOGSZ];
  unsigned long start_time = millis();
  addLog_P(LOG_LEVEL_DEBUG_MORE, "Func: GetLightSensorData Start");

  luxString = String(lightSensor.readLightLevel());

  snprintf_P(log, sizeof(log), PSTR("GetLightSensorData: Lux: %s"), luxString.c_str());
  addLog(LOG_LEVEL_INFO, log);

  unsigned long load_time = millis() - start_time;
  snprintf_P(log, sizeof(log), PSTR("Func: GetLightSensorData load time: %d"), load_time);
  addLog(LOG_LEVEL_DEBUG_MORE, log);
}
#endif



#ifdef BME280_ON
void GetBmeSensorData()
{
  char log[LOGSZ];
  unsigned long start_time = millis();
  addLog_P(LOG_LEVEL_DEBUG_MORE, "Func: GetBmeSensorData Start");

  temperatureString = String(bmeSensor.readTempC());
  snprintf_P(log, sizeof(log), PSTR("GetBmeSensorData: Temperature: %s C"), temperatureString.c_str());
  addLog(LOG_LEVEL_INFO, log);

  pressureString = String(bmeSensor.readFloatPressure()/133.3F);
  snprintf_P(log, sizeof(log), PSTR("GetBmeSensorData: Pressure: %s"), pressureString.c_str());
  addLog(LOG_LEVEL_INFO, log);

  humidityString = String(bmeSensor.readFloatHumidity());
  snprintf_P(log, sizeof(log), PSTR("GetBmeSensorData: Humidity: %s %"), humidityString.c_str());
  addLog(LOG_LEVEL_INFO, log);

  unsigned long load_time = millis() - start_time;
  snprintf_P(log, sizeof(log), PSTR("Func: GetBmeSensorData load time: %d"), load_time);
  addLog(LOG_LEVEL_DEBUG_MORE, log);
}
#endif



#ifdef SHT21_ON
void GetSHT21SensorData(){

  char log[LOGSZ];
  unsigned long start_time = millis();
  addLog_P(LOG_LEVEL_DEBUG_MORE, "Func: GetSHT21SensorData Start");

  myHTU21D.setResolution(HTU21D_RES_RH8_TEMP12);

  temperatureString = String(myHTU21D.readTemperature());
  snprintf_P(log, sizeof(log), PSTR("GetSHT21SensorData: Temperature: %s C"), temperatureString.c_str());
  addLog(LOG_LEVEL_INFO, log);

  humidityString = String(myHTU21D.readCompensatedHumidity());
  snprintf_P(log, sizeof(log), PSTR("GetSHT21SensorData: Humidity: %s %"), humidityString.c_str());
  addLog(LOG_LEVEL_INFO, log);

  unsigned long load_time = millis() - start_time;
  snprintf_P(log, sizeof(log), PSTR("Func: GetSHT21SensorData load time: %d"), load_time);
  addLog(LOG_LEVEL_DEBUG_MORE, log);
}
#endif



#ifdef DHT_ON
void GetDhtSensorData()
{
  char log[LOGSZ];
  unsigned long start_time = millis();
  addLog_P(LOG_LEVEL_DEBUG_MORE, "Func: GetDhtSensorData Start");

  float humidityData = dht.readHumidity();
  float temperatureData = dht.readTemperature();

  if (isnan(humidityData) || isnan(temperatureData)) {
    addLog_P(LOG_LEVEL_ERROR, "GetDhtSensorData: Error reading DHT!");
    return;
  } else {
    temperatureString = String(temperatureData);
    snprintf_P(log, sizeof(log), PSTR("GetDhtSensorData: Temperature: %s C"), temperatureString.c_str());
    addLog(LOG_LEVEL_INFO, log);

    humidityString = String(humidityData);
    snprintf_P(log, sizeof(log), PSTR("GetDhtSensorData: Humidity: %s %"), humidityString.c_str());
    addLog(LOG_LEVEL_INFO, log);

  }

  unsigned long load_time = millis() - start_time;
  snprintf_P(log, sizeof(log), PSTR("Func: GetDhtSensorData load time: %d"), load_time);
  addLog(LOG_LEVEL_DEBUG_MORE, log);
}
#endif


#ifdef DS18X20_ON
void SearchDS18x20Sensors() {

  if (searchDsSensorDone){
    return;
  }

  char log[LOGSZ];

  if (!ds.search(dsData[currentDsSensor].address)) {
    searchDsSensorDone = true;
    currentDsSensor = 0;
    ds.reset_search();
    MqttInitDS();
    return;
  } else if (!searchDsSensorDone) {
    findDsSensors ++;
  }

  if (OneWire::crc8(dsData[currentDsSensor].address, 7) != dsData[currentDsSensor].address[7]) {
    addLog_P(LOG_LEVEL_ERROR, "DS Sensor Address CRC is not valid!");
    return;
  }

  String addr = "";
  for (size_t i = 0; i < 8; i++)
  {
    addr += String(dsData[currentDsSensor].address[i], HEX);
  }
  dsData[currentDsSensor].addressString = addr;

  switch (dsData[currentDsSensor].address[0])
  {
    case 0x10:
        dsData[currentDsSensor].type = DS18S20;
        break;
    case 0x28:
        dsData[currentDsSensor].type = DS18B20;
        break;
    case 0x22:
        dsData[currentDsSensor].type = DS1822;
        break;
    default:
        dsData[currentDsSensor].type = UNKNOWN;
        return;
  }
  currentDsSensor ++;

  snprintf_P(log, sizeof(log), PSTR("DS: currentDsSensor:%d  findDsSensors:%d"), currentDsSensor, findDsSensors);
  addLog(LOG_LEVEL_INFO, log);
  SearchDS18x20Sensors();
}



void GetDS18x20SensorData(){

  if (findDsSensors == 0){
    addLog_P(LOG_LEVEL_ERROR, "DS Sensors Not Found!");
    searchDsSensorDone = false;
    currentDsSensor = 0;
    return;
  }

  byte i;
  byte data[12];

  if (!flag_ds_sensor_read_delay){
    flag_ds_sensor_read_delay = true;
    ds.reset();
    ds.select(dsData[currentDsSensor].address);
    ds.write(0x44, 1);        // start conversion, with parasite power on at the end
    timer.setTimeout(800, GetDS18x20SensorData);
    return;
  } else {
    flag_ds_sensor_read_delay = false;
  }

  ds.reset();
  ds.select(dsData[currentDsSensor].address);
  ds.write(0xBE);         // Read Scratchpad

  for (i = 0; i < 9; i++)
  {           // we need 9 bytes
      data[i] = ds.read();
  }

  if (OneWire::crc8(data, 8) != data[8]) {
    addLog_P(LOG_LEVEL_ERROR, "DS Sensor: Data CRC is not valid!");
    dsData[currentDsSensor].dsTemp = "none";
    nextDsSensor();
    return;
  }
  // Convert the data to actual temperature
  // because the result is a 16 bit signed integer, it should
  // be stored to an "int16_t" type, which is always 16 bits
  // even when compiled on a 32 bit processor.
  int16_t raw = (data[1] << 8) | data[0];
  if (dsData[currentDsSensor].type == DS18S20) {
    raw = raw << 3; // 9 bit resolution default
    if (data[7] == 0x10) {
        // "count remain" gives full 12 bit resolution
        raw = (raw & 0xFFF0) + 12 - data[6];
    }
  } else if (dsData[currentDsSensor].type == DS18B20 || dsData[currentDsSensor].type == DS1822) {
    byte cfg = (data[4] & 0x60);
    // at lower res, the low bits are undefined, so let's zero them
    if (cfg == 0x00) raw = raw & ~7;  // 9 bit resolution, 93.75 ms
    else if (cfg == 0x20) raw = raw & ~3; // 10 bit res, 187.5 ms
    else if (cfg == 0x40) raw = raw & ~1; // 11 bit res, 375 ms
    //// default is 12 bit resolution, 750 ms conversion time
  } else {
    addLog_P(LOG_LEVEL_ERROR, "Device is not a DS18x20 family device!");
  }

  dsData[currentDsSensor].dsTemp = String((float) raw / 16.0);
  dsDataPrint();
  nextDsSensor();
}



void nextDsSensor(){
  if (findDsSensors == currentDsSensor+1){
    currentDsSensor = 0;
  } else {
    currentDsSensor ++;
  }
}



void dsDataPrint(){

  char log[LOGSZ];
  unsigned long start_time = millis();
  addLog_P(LOG_LEVEL_DEBUG_MORE, "Func: dsDataPrint Start");

  String dsType = " ";

  switch (dsData[currentDsSensor].address[0]) {
    case 0x10:
      dsType = "DS18S20";  // or old DS1820
      break;
    case 0x28:
      dsType = "DS18B20";
      break;
    case 0x22:
      dsType = "DS1822";
      break;
    default:
      addLog_P(LOG_LEVEL_ERROR, "Device is not a DS18x20 family device!");
      return;
  }

  snprintf_P(log, sizeof(log), PSTR("DS type:%s  addr:%s  temp:%sC"), dsType.c_str(), dsData[currentDsSensor].addressString.c_str(), dsData[currentDsSensor].dsTemp.c_str());
  addLog(LOG_LEVEL_INFO, log);

  unsigned long load_time = millis() - start_time;
  snprintf_P(log, sizeof(log), PSTR("Func: dsDataPrint load time: %d"), load_time);
  addLog(LOG_LEVEL_DEBUG_MORE, log);
}
#endif //DS18X20_ON



#if defined(PZEM_ON)
bool GetPzemData(float data, String *val) {

  char log[LOGSZ];
  unsigned long start_time = millis();
  addLog_P(LOG_LEVEL_DEBUG_MORE, "Func: GetPzemData Start");

  if (data < 0.0) {
    addLog_P(LOG_LEVEL_ERROR, "GetPzemData: Error reading data!");
    pzem.setAddress(ip_pzem);
    pzem.setReadTimeout(500);
    pzemAlive = false;
    checkCount = 0;
    *val = "none";
    return false;
  } else if (pzem_current_read == PZEM_POWER || pzem_current_read == PZEM_ENERGY) {
    data = data * coil_ratio / 1000;
  } else if (pzem_current_read == PZEM_CURRENT) {
    data = data * coil_ratio;
  }
  *val = String(data);
  checkCount ++;
  if (checkCount >= 4) {
    pzemAlive = true;
    checkCount = 0;
  }

  unsigned long load_time = millis() - start_time;
  snprintf_P(log, sizeof(log), PSTR("Func: GetPzemData load time: %d"), load_time);
  addLog(LOG_LEVEL_DEBUG_MORE, log);

  return true;
}



void GetPzemSerialRead() {

  char log[LOGSZ];
  unsigned long start_time = millis();
  addLog_P(LOG_LEVEL_DEBUG_MORE, "Func: GetPzemSerialRead Start");

  switch (pzem_current_read) {
    case PZEM_VOLTAGE:
      if (GetPzemData(pzem.voltage(ip_pzem), &pzemVoltageString)) {
        snprintf_P(log, sizeof(log), PSTR("GetPzemSerialRead: Voltage: %s V"), pzemVoltageString.c_str());
        addLog(LOG_LEVEL_INFO, log);
      }
      pzem_current_read = PZEM_CURRENT;
      break;
    case PZEM_CURRENT:
      if (GetPzemData(pzem.current(ip_pzem), &pzemCurrentString)) {
        snprintf_P(log, sizeof(log), PSTR("GetPzemSerialRead: Current: %s A"), pzemCurrentString.c_str());
        addLog(LOG_LEVEL_INFO, log);
      }
      pzem_current_read = PZEM_POWER;
      break;
    case PZEM_POWER:
      if (GetPzemData(pzem.power(ip_pzem), &pzemPowerString)) {
        snprintf_P(log, sizeof(log), PSTR("GetPzemSerialRead: Power: %s W"), pzemPowerString.c_str());
        addLog(LOG_LEVEL_INFO, log);
      }
      pzem_current_read = PZEM_ENERGY;
      break;
    case PZEM_ENERGY:
      if (GetPzemData(pzem.energy(ip_pzem), &pzemEnergyString)) {
        snprintf_P(log, sizeof(log), PSTR("GetPzemSerialRead: Energy: %s Wh"), pzemEnergyString.c_str());
        addLog(LOG_LEVEL_INFO, log);
      }
      pzem_current_read = PZEM_VOLTAGE;
      break;
    default:
      pzem_current_read = PZEM_VOLTAGE;
  }

  unsigned long load_time = millis() - start_time;
  snprintf_P(log, sizeof(log), PSTR("Func: GetPzemSerialRead load time: %d"), load_time);
  addLog(LOG_LEVEL_DEBUG_MORE, log);
}



void PzemResetEnergy() {

  char log[LOGSZ];
  unsigned long start_time = millis();
  addLog_P(LOG_LEVEL_DEBUG_MORE, "Func: PzemResetEnergy Start");

  switch (pzem_reset_stage) {
    case PZEM_STAGE1:
      lightState = "ON";
      LightControl();
      pzem_reset_stage = PZEM_STAGE2;
      timer.setTimeout(6000, PzemResetEnergy);
      break;
    case PZEM_STAGE2:
      lightState = "OFF";
      LightControl();
      pzem_reset_stage = PZEM_STAGE3;
      timer.setTimeout(1000, PzemResetEnergy);
      break;
    case PZEM_STAGE3:
      lightState = "ON";
      LightControl();
      pzem_reset_stage = PZEM_STAGE4;
      timer.setTimeout(1000, PzemResetEnergy);
      break;
    case PZEM_STAGE4:
      lightState = "OFF";
      LightControl();
      pzem_reset_stage = PZEM_STAGE1;
      break;
    default:
      break;
  }

  unsigned long load_time = millis() - start_time;
  snprintf_P(log, sizeof(log), PSTR("Func: PzemResetEnergy load time: %d"), load_time);
  addLog(LOG_LEVEL_DEBUG_MORE, log);
}
#endif



#ifdef MHZ19_ON
int GetMHZ19() {
  char log[LOGSZ];

  // command to ask for data
  byte cmd[RESPONSE_SIZE] = {0xFF, 0x01, 0x86, 0x00, 0x00, 0x00, 0x00, 0x00, 0x79};
  char data[RESPONSE_SIZE];

  Serial.write(cmd, RESPONSE_SIZE); //request PPM CO2

  unsigned long startTime = millis();
  uint8_t len = 0;
  while((len < RESPONSE_SIZE) && (millis() - startTime < READ_TIMEOUT)) {
    if(Serial.available() > 0) {
      Serial.readBytes(data, RESPONSE_SIZE);
    }
  }

  if (data[0] != 0xFF) {
    addLog_P(LOG_LEVEL_ERROR, "Wrong starting byte from co2 sensor!");
    return -1;
  }

  if (data[1] != 0x86) {
    addLog_P(LOG_LEVEL_ERROR, "Wrong command from co2 sensor!");
    return -1;
  }

  int responseHigh = (int) data[2];
  int responseLow = (int) data[3];
  int ppm = (256 * responseHigh) + responseLow;
  mhz19PpmString = String(ppm);

  snprintf_P(log, sizeof(log), PSTR("GetMHZ19: CO2: %d PPM"), ppm);
  addLog(LOG_LEVEL_INFO, log);
  return ppm;
}
#endif // MHZ19_ON



void MotionDetect(){

  char log[LOGSZ];
  unsigned long start_time = millis();
  addLog_P(LOG_LEVEL_DEBUG_MORE, "Func: MotionDetect Start");

  if (digitalRead(atoi(JConf.motion_pin)) == HIGH) {
    addLog_P(LOG_LEVEL_INFO, "MotionDetect: movement detected");
    motionDetect = true;
    LightControl();
    if (atoi(JConf.mqtt_enable) == 1 && mqtt.connected()) {
      pubTopicMotionSensor.publish("1");
    }
  } else if (motionDetect){
    motionDetect = false;
    if (atoi(JConf.mqtt_enable) == 1 && mqtt.connected()) {
      pubTopicMotionSensor.publish("0");
    }
  }

  unsigned long load_time = millis() - start_time;
  snprintf_P(log, sizeof(log), PSTR("Func: MotionDetect load time: %d"), load_time);
  addLog(LOG_LEVEL_DEBUG_MORE, log);
}



String GetUptimeData(){

  char log[LOGSZ];
  unsigned long start_time = millis();
  addLog_P(LOG_LEVEL_DEBUG_MORE, "Func: GetUptimeData Start");

  //** Making Note of an expected rollover *****//
  if(millis()>=3000000000){
    HighMillis=1;
  }
  //** Making note of actual rollover **//
  if(millis()<=100000&&HighMillis==1){
    Rollover++;
    HighMillis=0;
  }

  long secsUp = millis()/1000;
  Second = secsUp%60;
  Minute = (secsUp/60)%60;
  Hour = (secsUp/(60*60))%24;
  Day = (Rollover*50)+(secsUp/(60*60*24));  //First portion takes care of a rollover [around 50 days]

  sprintf_P(value_buff, (const char *)F("%dd %02d:%02d"), Day, Hour, Minute);
  uptimeString = String(value_buff);

  snprintf_P(log, sizeof(log), PSTR("GetUptimeData: Uptime: %s:%d%d"), uptimeString.c_str(), Second/10, Second%10);
  addLog(LOG_LEVEL_INFO, log);

  unsigned long load_time = millis() - start_time;
  snprintf_P(log, sizeof(log), PSTR("Func: GetUptimeData load time: %d"), load_time);
  addLog(LOG_LEVEL_DEBUG_MORE, log);

  return value_buff;
}



#ifdef NTP_ON
void NTPSettingsUpdate(){
  if (atoi(JConf.ntp_enable) == 1) {
    ntpLastUpdateTime = millis();
    timeClient.end();
    timeClient.setUpdateServer(JConf.ntp_server);
    timeClient.setTimeOffset(atoi(JConf.my_time_zone) * 60 * 60);
    timeClient.setUpdateInterval(60*60*1000);
    timeClient.begin();
  }
}
#endif
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
void loop() {

  if (fading[0].cycleEnd != fading[0].cycleNow || fading[1].cycleEnd != fading[1].cycleNow) {
    FadeSwitchLoop();
  } else {
    #ifdef USE_WEBSERVER
      WebServer.handleClient();  // handle web server
    #endif // USE_WEBSERVER

    timer.run();

    if (WiFi.status() == WL_CONNECTED && atoi(JConf.mqtt_enable) == 1) {
      if (mqtt.connected()){
        mqtt.processPackets(100);
      }
    }

    if (atoi(JConf.motion_sensor_enable) == 1 && motionDetect == false){
      MotionDetect();
    }

    if (lightState == "AUTO" || lightState2 == "AUTO"){
      LightControl();
    }

    #ifdef UART_ON
      Uart.serialEvent();
    #endif

  }

  #ifdef NTP_ON
    if ( atoi(JConf.ntp_enable) == 1 && millis() - ntpLastUpdateTime < NTP_ERROR_TIME ) {
      if (timeClient.update()) ntpLastUpdateTime = millis();
      timer.restartTimer(ntpTimer);
    }
  #endif

  yield();
}

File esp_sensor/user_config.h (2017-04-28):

#ifndef USER_CONFIG_H
#define USER_CONFIG_H

#include "json_config.h"
JsonConf JConf;

// --------------- Supported Sensors (Uncomment for Enable) -------------------
#define DHT_ON
#define BME280_ON
#define SHT21_ON
#define BH1750_ON

//------------------PZEM Sensor-------------------------------------------------
#define PZEM_ON

#ifdef PZEM_ON
  bool pzemAlive = false;
  float coil_ratio = 1.84; // Если используем разные катушки, подбираем коэффициент
  // Кол-во удачных считываний показаний, прежде чем их отправлять. (if >= 4 send)
  uint8_t checkCount = 0;
#endif //PZEM_ON
//------------------------------------------------------------------------------

//------------------DS18X20 Sensors---------------------------------------------
#define DS18X20_ON

#ifdef DS18X20_ON
  #define DS18X20_PIN 14
  #define MAX_DS_SENSORS 2
#endif //DS18X20_ON
//------------------------------------------------------------------------------

//------------------MH-Z19 Sensor-----------------------------------------------
#define MHZ19_ON

#define RESPONSE_SIZE 9   // Размер пакета
#define READ_TIMEOUT 300  // Время ожидания ответа от датчика
//------------------------------------------------------------------------------


//#define DEBUG

//#define RESET_BUTTON_ON   //Функционал сброса конфига по кнопке при загрузке модуля

//#define REBOOT_ON

//#define LCD_ON   //Дисплей с I2C

//#define BOILER_ON   //Котел отопления


//------------------NTP Client--------------------------------------------------
#define NTP_ON

#ifdef NTP_ON
  #define NTP_ERROR_TIME 30000 // Если за это время не смогли обновить время, засыпаем
  #define NTP_TIME_SLEEP 600000 // Время сна
  int ntpTimer = 0;
  unsigned long ntpLastUpdateTime = 0;
#endif //NTP_ON
//------------------------------------------------------------------------------

//------------------Encoder-----------------------------------------------------
//#define ENCODER_ON                              // Включить поддержку энкодера

#ifdef ENCODER_ON
  uint8_t encoderDirection = 0;                 // Направление поворота энкодера
  bool encoderFlagA = false;
  bool encoderFlagB = false;
  int encoderResetTimer = 0;
  int encoderResetInterval = 2000;                     // Интервал сброса флагов
#endif //ENCODER_ON
//------------------------------------------------------------------------------

#define USE_WEBSERVER

#define FADE_PINS 2
#define UP true
#define DOWN false


#define TOPSZ                  60           // Max number of characters in topic string
#define MESSZ                  128          // Max number of characters in message string
#define LOGSZ                  128          // Max number of characters in log string
#define MQTTSZ                 50           // Max number of characters in MQTT topic string

#define USE_WEBSERVER                       // Enable web server and wifi manager
#define MAX_LOG_LINES          30           // Max number of lines in weblog


#define SUB_PREFIX             "cmnd"       // Sonoff devices subscribe to:- cmnd/MQTT_TOPIC and cmnd/MQTT_GRPTOPIC


String Log[MAX_LOG_LINES];            // Web log buffer
byte logidx = 0;                      // Index in Web log buffer

struct TIME_T {
  uint8_t       Second;
  uint8_t       Minute;
  uint8_t       Hour;
  uint8_t       Wday;      // day of week, sunday is day 1
  uint8_t       Day;
  uint8_t       Month;
  char          MonthName[4];
  uint16_t      Year;
  unsigned long Valid;
} rtcTime;

WiFiClient espClient;


Adafruit_MQTT_Client mqtt = Adafruit_MQTT_Client(&espClient, JConf.mqtt_server, atoi(JConf.mqtt_port), JConf.mqtt_user, JConf.mqtt_pwd);

Adafruit_MQTT_Publish pubTopicLightType = Adafruit_MQTT_Publish(&mqtt, JConf.publish_topic);
Adafruit_MQTT_Publish pubTopicLightType2 = Adafruit_MQTT_Publish(&mqtt, JConf.publish_topic);
Adafruit_MQTT_Publish pubTopicMotionSensor = Adafruit_MQTT_Publish(&mqtt, JConf.publish_topic);
Adafruit_MQTT_Publish pubTopicMotionSensorTimer = Adafruit_MQTT_Publish(&mqtt, JConf.publish_topic);
Adafruit_MQTT_Publish pubTopicMotionSensorTimer2 = Adafruit_MQTT_Publish(&mqtt, JConf.publish_topic);

Adafruit_MQTT_Publish pubTopicLux = Adafruit_MQTT_Publish(&mqtt, JConf.publish_topic);
Adafruit_MQTT_Publish pubTopicTemperature = Adafruit_MQTT_Publish(&mqtt, JConf.publish_topic);
Adafruit_MQTT_Publish pubTopicHumidity = Adafruit_MQTT_Publish(&mqtt, JConf.publish_topic);
Adafruit_MQTT_Publish pubTopicPressure = Adafruit_MQTT_Publish(&mqtt, JConf.publish_topic);
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

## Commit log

2016-01-15 Add Arduino sketch
2016-01-15 Add Eagle and Gerber files
    [esp.brd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]
2016-01-18 Добавлена возможность настройки статического адреса
2016-01-19 изменение сохранения настроек статического ip
2016-01-19 fix staticIpMode При сохранении страницы конфигурации пароль заменялся на звездочки. проверка пароля на наличие 8 звездочек
    [esp_sensor.ino]
2016-01-21 Add OpenHab config and screens
    [openhab.cfg]
2016-01-22 Fix: Static ip OFF
    [esp_sensor.ino]
2016-01-22 Saving RAM using F(), add ajax update pressure
2016-01-22 fix F() for XML String
    Conflicts:
    esp_sensor/esp_sensor.ino
    [esp_sensor.ino]
2016-01-23 Add Ajax on web "Control Pins", add control 2 Led Strip
2016-01-26 fix error in function MotionDetect() Ошибка вызывала перезагрузку устройства при отправке сообщения по MQTT
    [esp_sensor.ino]
2016-01-27 fix json load in loadConfig()
    [esp_sensor.ino]
2016-01-28 Fix web config light_off_delay
    [esp_sensor.ino]
2016-01-31 fix status on web page
    [esp_sensor.ino]
2016-02-02 update func UART
2016-02-03 add parse UART command
2016-02-04 fix web page Analog pin
    [ESP_UART.cpp, ESP_UART.h, esp_sensor.ino]
2016-02-07 Add web page "Analog Pins UART"
2016-02-08 Add: Display voltage on status web page
2016-02-10 fix: conflict my lib name ESP_UART.h with cores/esp8266/uart.h
    [MY_ESP_UART.cpp, MY_ESP_UART.h, esp_sensor.ino]
2016-02-10 fix: remove excess includes in MY_ESP_UART.h
    [MY_ESP_UART.h]
2016-02-12 processing fix save config
    [esp_sensor.ino, json_config.cpp]
2016-02-17 Fix: Static IP mode
    [esp_sensor.ino]
2016-02-17 Fix: checkbox Static_IP_Mode not save state
    [esp_sensor.ino]
2016-02-18 Fix: save state checkbox Static IP Mode
    [esp_sensor.ino]
2016-02-19 Fix: Empty values MQTT User and password not saved
    [esp_sensor.ino]
2016-02-22 Fix: hang device if sensor BME280 not enable
    [esp_sensor.ino]
2016-02-25 Fix: ntp_enable not save in config.json
    [json_config.cpp]
2016-02-25 Fix: On/Off ntp time
    [esp_sensor.ino]
2016-02-26 Add: On/Off Sensors: BME280, SHT21, BH1750, Motion Sensor
2016-02-26 Fix: Reconfigure NTP service after boot
    [esp_sensor.ino]
2016-03-03 Fix: Wi-Fi mode AP resetting connect
    [esp_sensor.ino]
2016-03-04 Fix: Wi-Fi AP_STA reseting connect
    [esp_sensor.ino, json_config.cpp]
2016-03-13 Fix: Smooth Light ON
    [esp_sensor.ino]
2016-03-14 Fix: Wi-Fi Safe mode
    [esp_sensor.ino]
2016-03-14 Fix: replace sta_pwd on ap_pwd
    [esp_sensor.ino]
2016-03-15 Fix: Smooth Ligth Disable
    [esp_sensor.ino]
2016-09-28 Fix for updated PZEM library
    [esp_sensor.ino]
2016-10-09 Fix read data for PZEM
    [esp_sensor.ino]
2016-10-09 Add func for reset energy PZEM
    [esp_sensor.ino]
2016-10-09 Change delays for reset energy PZEM
    [esp_sensor.ino]
2016-10-17 Fix mqtt callback for PZEM
    [esp_sensor.ino]
2016-10-26 Fix sending move detect if motion sensor disable
    [esp_sensor.ino]
2016-10-26 Add: config reset by pressing a button
    [esp_sensor.ino, json_config.cpp]
2016-10-27 Fix WiFi func, MQTT Subscribe
    [esp_sensor.ino, json_config.cpp]
2016-11-04 Replace MQTT library. Part1
    [esp_sensor.ino]
2016-11-04 Replace MQTT library. Part2
    [esp_sensor.ino]
2016-11-04 Replace MQTT library. Part3
    [esp_sensor.ino]
2016-11-07 Save DHT pin in Json config
2016-11-08 Fixed Ligth Control if bh1750 sensor disable
    [esp_sensor.ino]
2016-11-09 Replace library for DHT
    [esp_sensor.ino]
2016-11-09 Fix MQTT auth on/off
    [esp_sensor.ino, json_config.cpp]
2016-11-09 Fix read DHT Sensor data
    [esp_sensor.ino]
2016-11-10 Add debug info for DHT Sensor
2016-11-24 Fix send MQTT data for DS18X20
    [esp_sensor.ino, web.ino]
2016-11-27 Fix NTP Update. Need to update library NtpClient
    [esp_sensor.ino, support.ino]
2016-12-08 Fix: Error if Connecting to MQTT false
    [esp_sensor.ino]
2016-12-18 Add support MH-Z19 Sensor
2016-12-19 Test support display 1602 I2C
2016-12-23 Added Encoder support
2017-01-11 Fixed loadinig page </wificonf>
    [web.ino]
2017-01-11 Added Wire.h and favicon.ico
2017-01-11 Fixed NTP Client connecting
    [esp_sensor.ino, user_config.h]
2017-01-11 Added Arduino libraries
2017-01-21 Fix MQTT Publish data for DS18X20
    [esp_sensor.ino, user_config.h]
2017-01-22 Fix DS18x20 get data
    [esp_sensor.ino, user_config.h]
2017-02-02 Change movement func.
    По MQTT теперь отправляется 0\1 вместо ON\OFF
    Добавил отправку сообщения при прекращении движения (0)
2017-03-22 Срабатывание для обеих ламп
2017-03-23 Added: Boiler control Added: Test I2C LCD support Fix: Hang on web page <wificonf>
    [esp_sensor.ino, json_config.cpp, support.ino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]
2017-04-26 Issue 32 Added check PZEM alive
    [esp_sensor.ino, user_config.h]
2017-04-27 Issue: 32 All PZEM data change to "none"
    [esp_sensor.ino]
2017-04-28 Issue: 32 Fix: sending "none" in MQTT
    [esp_sensor.ino, user_config.h]
